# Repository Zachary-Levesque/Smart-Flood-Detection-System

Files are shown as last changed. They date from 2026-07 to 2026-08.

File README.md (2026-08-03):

# Smart Flood Detection System

**ESP32 C3 Mini based IoT flood detection system.** It monitors water level in real time, triggers a local buzzer and LED alarm, sends a Telegram alert over WiFi, and keeps recent events available.

## Motivation

After experiencing a basement flood for the second time in 14 months, I wanted a system that could catch water leakage early and notify me immediately. This project applies embedded design, sensing, connectivity, and reliability thinking to a real home safety problem.

## Overview

This system continuously monitors water presence using a Seeed Studio Grove Water Level Sensor connected to an ESP32 C3 Mini over I2C. When water is detected above the calibrated threshold, the system:

1. Triggers the local buzzer and LED.
2. Sends a Telegram notification when WiFi and credentials are available.
3. Logs the event with a timestamp for later serial review.

The design prioritizes reliability and fail safe behavior.

## System Architecture

Completed Smart Flood Detection System

See [hardware/block_diagram.md](hardware/block_diagram.md) for the completed system image.

## Hardware

1. **Microcontroller:** ESP32 C3 Mini.
2. **Sensor:** Seeed Studio Grove Water Level Sensor 101020635.
3. **Local alert:** Buzzer and status LED.
4. **Power:** 5 V USB wall adapter.
5. **Enclosure:** Simple plastic project box.
6. **PCB:** Simple carrier PCB in [hardware/PCB](hardware/PCB).

## Bill Of Materials

The simple part list is in [hardware/bill_of_materials.md](hardware/bill_of_materials.md).

## Firmware

Firmware is developed for the ESP32 C3 Mini using ESP IDF. It handles:

1. Periodic I2C sensor polling with debounce logic.
2. WiFi connection management and reconnect handling.
3. Threshold based water detection.
4. Local event logging.
5. Task watchdog coverage.
6. Telegram alert delivery when configured.

The local buzzer and LED path is intentionally independent of WiFi. Sensor events are delivered to the local alarm queue before any optional remote alert queue.

## Alerting And Connectivity

When the water threshold is exceeded, the firmware can send a Telegram bot notification directly over HTTPS using ESP IDF `esp_http_client`. If WiFi is unavailable or credentials are not configured, the remote alert is skipped and the local alarm remains active.

## Setup And Installation

Install and source the ESP IDF toolchain, then build, flash, and monitor the firmware from the `firmware` folder. Replace the `CHANGE_ME` values in `firmware/main/app_config.h` locally before flashing. Do not commit real WiFi or Telegram credentials.

## Wiring Diagram

See [hardware/wiring.md](hardware/wiring.md) for the simple pin map.

## Testing And Validation

To ensure this system performs reliably in a real flood scenario, testing includes:

1. Sensor accuracy testing with known dry, damp, wet, and submerged states.
2. False alarm testing with humidity and brief splashes.
3. Connectivity loss testing to confirm the local alarm still triggers without WiFi.
4. Power interruption testing with the selected backup power method.
5. End to end alert latency testing.

Use [hardware/test_plan.md](hardware/test_plan.md) for the simple test steps.

## Results

The prototype design and firmware are complete in this repository. The completed system is implemented and live in my basement!

## Repository Structure

```
Smart Flood Detection System
firmware    ESP32 C3 Mini source code
hardware    Block diagram, part list, wiring, PCB, and test plan
LICENSE
README.md
```

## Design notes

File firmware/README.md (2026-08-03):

# Firmware

This is the ESP IDF project for the Smart Flood Detection System, targeting the ESP32 C3 Mini.

## Task Architecture

The firmware is split into independent FreeRTOS tasks. Sensor state changes are sent to dedicated queues so the local alarm path remains isolated from networking.

1. `sensor_task` polls the Seeed Studio Grove Water Level Sensor over I2C, debounces readings, logs state changes, and sends each `system_event_t` to the local alarm queue first and the remote alert queue second.
2. `alarm_task` consumes its dedicated queue and drives the local buzzer and LED. It has no dependency on WiFi or networking.
3. `alert_task` consumes a separate queue and sends Telegram HTTPS alerts only when `wifi_manager_is_connected()` is true.
4. `wifi_manager` connects to the configured access point and handles automatic reconnect after drops.
5. `event_log` stores timestamped water state events in a RAM ring buffer and can dump the log over serial.

This separation is deliberate. The primary safety function is the local alarm, and it must not depend on remote alerting.

## Production Hardening

1. WiFi credentials are hardcoded in `app_config.h` for the prototype. A production build should use NVS backed WiFi provisioning with BLE or SoftAP setup.
2. `WATER_LEVEL_THRESHOLD_PERCENT` must be set from level readings captured for dry, damp, wet, and submerged states.
3. Long term deployment should use perfboard or a PCB in an enclosure.

## Calibration And Diagnostics

1. Hold `CALIBRATION_MODE_GPIO` low at boot, or set `SENSOR_CALIBRATION_FORCE` to `1`, to stream water level readings over serial while the firmware runs.
2. Hold `EVENT_LOG_DUMP_GPIO` low, or set `EVENT_LOG_DUMP_ON_BOOT` to `1`, to dump the RAM event log over serial.
3. `sensor_logic.c/.h` contains pure threshold and debounce helpers intended for reuse from an ESP IDF unit test app.

## Remote Alerting

Telegram alerting is implemented in `alert_task`. Fill in `TELEGRAM_BOT_TOKEN` and `TELEGRAM_CHAT_ID` in `app_config.h` locally before flashing. Real credentials should not be committed.

## Building

Requires the ESP IDF toolchain installed and sourced. Set the target to esp32c3 before building.

```
idf.py menuconfig
idf.py build
idf.py flash monitor
```

## File Overview

```
firmware
CMakeLists.txt          top level project build file
sdkconfig.defaults      default build configuration
main
  CMakeLists.txt        component build file
  app_config.h          pins, thresholds, WiFi config, shared types
  main.c                app_main wires up tasks
  sensor_task.c/.h      I2C water sensor polling and event fanout
  sensor_logic.c/.h     unit testable threshold and debounce helpers
  alarm_task.c/.h       local buzzer and LED
  alert_task.c/.h       Telegram HTTPS alerting
  event_log.c/.h        RAM event log and serial dump
  wifi_manager.c/.h     WiFi connection and reconnect handling
```

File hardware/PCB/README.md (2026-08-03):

# PCB

This folder contains a simple carrier PCB for the Smart Flood Detection System.

## What The PCB Does

1. Connects the ESP32 C3 Mini to the Grove water level sensor.
2. Connects GPIO6 to the buzzer.
3. Connects GPIO7 to the LED through a 220 ohm resistor.
4. Keeps the circuit cleaner than a breadboard.

## Connectors

1. J1 is the ESP32 C3 Mini signal header.
2. J2 is the Grove sensor connector.
3. J3 is the buzzer connector.
4. R1 is the 220 ohm LED resistor.
5. D1 is the status LED.

## J1 Pin Order

1. 3V3
2. GND
3. GPIO4 SDA
4. GPIO5 SCL
5. GPIO6 buzzer
6. GPIO7 LED

## J2 Grove Pin Order

1. SCL
2. SDA
3. 3V3
4. GND

## Files

1. `gerbers` contains the fabrication files.
2. `board_notes.md` explains the layout in plain language.

Check the exact ESP32 C3 Mini board dimensions before ordering. This is a simple carrier board, not a custom ESP32 module layout.

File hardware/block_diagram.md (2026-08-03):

# Completed System Image

Completed Smart Flood Detection System

The Grove water sensor connects to the ESP32 C3 Mini with I2C. The ESP32 C3 Mini turns on the local buzzer and LED when water is detected. If WiFi is working, it also sends a Telegram alert.

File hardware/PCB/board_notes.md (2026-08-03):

# Board Notes

Board size is 50 mm by 40 mm.

The ESP32 C3 Mini plugs in through the J1 header or connects with short wires. The Grove sensor plugs into J2. The buzzer plugs into J3. The LED and resistor are mounted on the board.

This PCB is meant to replace the breadboard wiring for the current project.

Before ordering, confirm these points:

1. Your ESP32 C3 Mini exposes GPIO4, GPIO5, GPIO6, GPIO7, 3V3, and GND.
2. Your Grove cable pin order matches SCL, SDA, 3V3, and GND.
3. Your buzzer module can be driven from GPIO6.
4. Your LED uses a 220 ohm resistor.

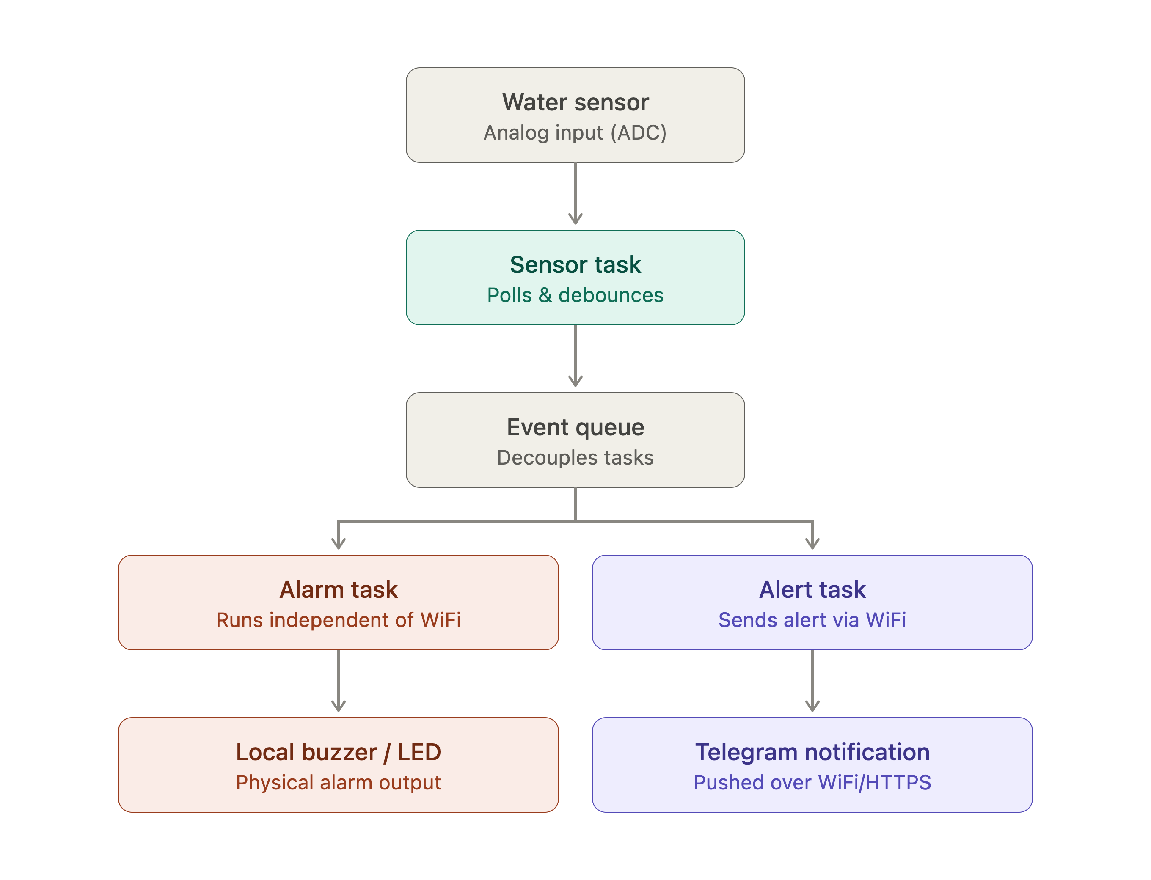
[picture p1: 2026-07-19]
flood_detection_system_architecture.png

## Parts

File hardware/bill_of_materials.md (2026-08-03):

# Bill Of Materials

## Required Parts

1. ESP32 C3 Mini.
2. Seeed Studio Grove Water Level Sensor 101020635.
3. Active buzzer module.
4. LED.
5. 220 ohm resistor for the LED.
6. Jumper wires.
7. Custom carrier PCB.
8. USB cable.
9. 5 V USB power adapter.
10. Plastic enclosure.

## Optional Parts

1. USB battery backup.
2. Extra mounting tape, screws, or zip ties.

## Notes

1. Use the sensor with 3.3 V power from the ESP32 C3 Mini.
2. Keep the ESP32 and wiring above the floor.
3. Keep the water sensor at the lowest point where water should be detected.

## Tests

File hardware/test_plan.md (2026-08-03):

# Test Plan

1. Power on the ESP32 with the sensor dry. The buzzer and LED should stay off.
2. Touch the Grove sensor with water. The buzzer and LED should turn on.
3. Dry the sensor. The buzzer and LED should turn off.
4. Turn off WiFi and wet the sensor. The local alarm should still work.
5. Turn WiFi back on and confirm the Telegram alert works.
6. Leave the system running for a few hours and check for false alarms.

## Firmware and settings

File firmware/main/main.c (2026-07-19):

#include "app_config.h"
#include "alert_task.h"
#include "sensor_task.h"
#include "alarm_task.h"
#include "event_log.h"
#include "wifi_manager.h"

#include "freertos/FreeRTOS.h"
#include "freertos/queue.h"
#include "esp_err.h"
#include "esp_log.h"
#include "esp_task_wdt.h"

static void configure_task_watchdog(void)
{
    esp_task_wdt_config_t wdt_config = {
        .timeout_ms = TASK_WATCHDOG_TIMEOUT_MS,
        .idle_core_mask = 0,
        .trigger_panic = true,
    };

    esp_err_t err = esp_task_wdt_init(&wdt_config);
    if (err == ESP_ERR_INVALID_STATE) {
        ESP_LOGW("main", "Task watchdog already initialized");
    } else {
        ESP_ERROR_CHECK(err);
    }
}

static const char *TAG = "main";

void app_main(void)
{
    ESP_LOGI(TAG, "Smart Flood Detection System starting up");
    event_log_init();
    configure_task_watchdog();

    // Dedicated alarm queue: sensor_task publishes local-alarm events here
    // first. Remote alerting has a separate queue so network work cannot
    // consume, gate, or delay the local alarm path.
    QueueHandle_t alarm_event_queue = xQueueCreate(10, sizeof(system_event_t));
    QueueHandle_t alert_event_queue = xQueueCreate(10, sizeof(system_event_t));
    if (alarm_event_queue == NULL || alert_event_queue == NULL) {
        ESP_LOGE(TAG, "Failed to create event queues, halting");
        return;
    }

    // WiFi is started but never gated on — the local alarm and
    // sensor logic run regardless of network state. This is the
    // core fail-safe design principle of this project: connectivity
    // is a "nice to have" for remote alerting, not a dependency for
    // the physical safety mechanism.
    wifi_manager_start();

    event_log_dump_task_start();
    alarm_task_start(alarm_event_queue);
    alert_task_start(alert_event_queue);
    sensor_task_start(alarm_event_queue, alert_event_queue);
}

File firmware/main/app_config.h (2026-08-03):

#pragma once

#include <stdint.h>

#include "driver/gpio.h"
#include "driver/i2c.h"

// =====================================================================
// Pin configuration
// Prototype pin assignments. These match hardware/wiring.md.
// =====================================================================
#define I2C_PORT                    I2C_NUM_0
#define I2C_SDA_GPIO                GPIO_NUM_4
#define I2C_SCL_GPIO                GPIO_NUM_5
#define BUZZER_GPIO                 GPIO_NUM_6
#define STATUS_LED_GPIO             GPIO_NUM_7
#define CALIBRATION_MODE_GPIO       GPIO_NUM_0   // hold low at boot to stream level readings
#define EVENT_LOG_DUMP_GPIO         GPIO_NUM_0   // hold low to dump recent events over serial

// =====================================================================
// Sensor thresholds
// Calibrate this against real level readings from calibration mode:
// 1. Flash firmware, hold CALIBRATION_MODE_GPIO low at boot, and open monitor.
// 2. Record water level percent for dry, damp, wet, and submerged states.
// 3. Set WATER_LEVEL_THRESHOLD_PERCENT to the level that should trigger alarm.
// =====================================================================
#define GROVE_WATER_LOW_ADDR        0x77
#define GROVE_WATER_HIGH_ADDR       0x78
#define GROVE_WATER_TOUCH_THRESHOLD 100
#define WATER_LEVEL_THRESHOLD_PERCENT 10
#define SENSOR_POLL_INTERVAL_MS     2000    // how often to sample the sensor
#define SENSOR_DEBOUNCE_SAMPLES     3       // consecutive samples required to confirm a reading
#define SENSOR_CALIBRATION_FORCE    0       // set to 1 to always stream level readings

// =====================================================================
// Runtime diagnostics
// =====================================================================
#define EVENT_LOG_CAPACITY          32
#define EVENT_LOG_DUMP_ON_BOOT      0       // set to 1 to dump RAM log at startup
#define EVENT_LOG_DUMP_GPIO_ENABLED 1       // hold EVENT_LOG_DUMP_GPIO low at boot to dump
#define EVENT_LOG_DUMP_POLL_MS      1000

// =====================================================================
// Watchdog
// =====================================================================
#define TASK_WATCHDOG_TIMEOUT_MS    10000

// =====================================================================
// WiFi configuration
// Prototype credentials. For production, move credentials to NVS backed
// provisioning before deployment.
// ESP IDF WiFi provisioning examples support BLE or SoftAP flows that store
// credentials in NVS.
// =====================================================================
#define WIFI_SSID                   "CHANGE_ME"
#define WIFI_PASSWORD                "CHANGE_ME"
#define WIFI_MAX_RETRY               5
#define WIFI_RETRY_BACKOFF_MS        30000

// =====================================================================
// Telegram alerting
// Fill these in locally. Do not commit real bot tokens or chat IDs.
// =====================================================================
#define TELEGRAM_BOT_TOKEN          "CHANGE_ME"
#define TELEGRAM_CHAT_ID            "CHANGE_ME"
#define TELEGRAM_ALERT_MESSAGE      "Water detected by Smart Flood Detection System"

// =====================================================================
// Event types passed between tasks via queue
// =====================================================================
typedef enum {
    EVENT_WATER_NORMAL = 0,
    EVENT_WATER_DETECTED,
} system_event_t;

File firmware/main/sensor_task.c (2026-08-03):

#include "sensor_task.h"
#include "app_config.h"
#include "event_log.h"
#include "sensor_logic.h"

#include "freertos/FreeRTOS.h"
#include "freertos/task.h"
#include "driver/gpio.h"
#include "driver/i2c.h"
#include "esp_err.h"
#include "esp_log.h"
#include "esp_task_wdt.h"

static const char *TAG = "sensor_task";

typedef struct {
    QueueHandle_t alarm_event_queue;
    QueueHandle_t alert_event_queue;
} sensor_task_config_t;

static esp_err_t read_sensor_section(uint8_t address, uint8_t *data, size_t length)
{
    return i2c_master_read_from_device(I2C_PORT,
                                       address,
                                       data,
                                       length,
                                       pdMS_TO_TICKS(100));
}

static int count_touched_sections(const uint8_t *data, size_t length)
{
    int touched = 0;
    for (size_t i = 0; i < length; i++) {
        if (data[i] > GROVE_WATER_TOUCH_THRESHOLD) {
            touched++;
        }
    }
    return touched;
}

static int read_water_level_percent(void)
{
    uint8_t low_data[8] = {0};
    uint8_t high_data[12] = {0};

    esp_err_t low_err = read_sensor_section(GROVE_WATER_LOW_ADDR, low_data, sizeof(low_data));
    esp_err_t high_err = read_sensor_section(GROVE_WATER_HIGH_ADDR, high_data, sizeof(high_data));
    if (low_err != ESP_OK || high_err != ESP_OK) {
        ESP_LOGW(TAG, "Water sensor I2C read failed low=%s high=%s",
                 esp_err_to_name(low_err),
                 esp_err_to_name(high_err));
        return 0;
    }

    int touched = count_touched_sections(low_data, sizeof(low_data)) +
                  count_touched_sections(high_data, sizeof(high_data));
    return touched * 5;
}

static bool calibration_mode_enabled(void)
{
#if SENSOR_CALIBRATION_FORCE
    return true;
#else
    return gpio_get_level(CALIBRATION_MODE_GPIO) == 0;
#endif
}

static void configure_calibration_gpio(void)
{
    gpio_reset_pin(CALIBRATION_MODE_GPIO);
    gpio_set_direction(CALIBRATION_MODE_GPIO, GPIO_MODE_INPUT);
    gpio_set_pull_mode(CALIBRATION_MODE_GPIO, GPIO_PULLUP_ONLY);
}

static void configure_i2c(void)
{
    i2c_config_t config = {
        .mode = I2C_MODE_MASTER,
        .sda_io_num = I2C_SDA_GPIO,
        .scl_io_num = I2C_SCL_GPIO,
        .sda_pullup_en = GPIO_PULLUP_ENABLE,
        .scl_pullup_en = GPIO_PULLUP_ENABLE,
        .master.clk_speed = 100000,
    };

    ESP_ERROR_CHECK(i2c_param_config(I2C_PORT, &config));
    ESP_ERROR_CHECK(i2c_driver_install(I2C_PORT, config.mode, 0, 0, 0));
}

static void publish_event(QueueHandle_t queue, system_event_t event, const char *queue_name)
{
    if (queue == NULL) {
        return;
    }

    if (xQueueSend(queue, &event, pdMS_TO_TICKS(100)) != pdTRUE) {
        ESP_LOGW(TAG, "Failed to enqueue event for %s (queue full)", queue_name);
    }
}

static void sensor_task(void *pvParameters)
{
    sensor_task_config_t *config = (sensor_task_config_t *) pvParameters;
    ESP_ERROR_CHECK(esp_task_wdt_add(NULL));

    configure_i2c();
    configure_calibration_gpio();

    sensor_debounce_state_t debounce;
    sensor_debounce_init(&debounce);

    ESP_LOGI(TAG, "Sensor task started, polling every %d ms", SENSOR_POLL_INTERVAL_MS);

    while (1) {
        int level_percent = read_water_level_percent();

        if (calibration_mode_enabled()) {
            ESP_LOGI(TAG, "Calibration water level: %d percent", level_percent);
        }

        bool changed = false;
        system_event_t current_state = sensor_debounce_update(&debounce,
                                                              level_percent,
                                                              WATER_LEVEL_THRESHOLD_PERCENT,
                                                              SENSOR_DEBOUNCE_SAMPLES,
                                                              &changed);

        if (changed) {
            ESP_LOGI(TAG, "Water state changed: %s (level=%d percent)",
                     system_event_to_string(current_state),
                     level_percent);

            event_log_record(current_state);
            publish_event(config->alarm_event_queue, current_state, "alarm");
            publish_event(config->alert_event_queue, current_state, "alert");
        }

        ESP_ERROR_CHECK(esp_task_wdt_reset());
        vTaskDelay(pdMS_TO_TICKS(SENSOR_POLL_INTERVAL_MS));
    }
}

void sensor_task_start(QueueHandle_t alarm_event_queue, QueueHandle_t alert_event_queue)
{
    static sensor_task_config_t config;
    config.alarm_event_queue = alarm_event_queue;
    config.alert_event_queue = alert_event_queue;

    xTaskCreate(sensor_task, "sensor_task", 4096, (void *) &config, 5, NULL);
}

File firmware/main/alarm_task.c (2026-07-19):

#include "alarm_task.h"
#include "app_config.h"

#include "freertos/FreeRTOS.h"
#include "freertos/task.h"
#include "driver/gpio.h"
#include "esp_err.h"
#include "esp_log.h"
#include "esp_task_wdt.h"

static const char *TAG = "alarm_task";

static void configure_outputs(void)
{
    gpio_reset_pin(BUZZER_GPIO);
    gpio_set_direction(BUZZER_GPIO, GPIO_MODE_OUTPUT);

    gpio_reset_pin(STATUS_LED_GPIO);
    gpio_set_direction(STATUS_LED_GPIO, GPIO_MODE_OUTPUT);
}

static void set_alarm_state(bool active)
{
    gpio_set_level(BUZZER_GPIO, active ? 1 : 0);
    gpio_set_level(STATUS_LED_GPIO, active ? 1 : 0);
}

// This task is intentionally simple and self-contained: it only
// depends on the event queue, not on WiFi/network state, so a local
// alarm still fires during a network outage.
static void alarm_task(void *pvParameters)
{
    QueueHandle_t event_queue = (QueueHandle_t) pvParameters;
    ESP_ERROR_CHECK(esp_task_wdt_add(NULL));

    configure_outputs();
    set_alarm_state(false);

    ESP_LOGI(TAG, "Alarm task started");

    system_event_t event;
    while (1) {
        if (xQueueReceive(event_queue, &event, pdMS_TO_TICKS(1000)) == pdTRUE) {
            bool active = (event == EVENT_WATER_DETECTED);
            ESP_LOGI(TAG, "Setting local alarm state: %s", active ? "ON" : "OFF");
            set_alarm_state(active);
        }
        ESP_ERROR_CHECK(esp_task_wdt_reset());
    }
}

void alarm_task_start(QueueHandle_t event_queue)
{
    xTaskCreate(alarm_task, "alarm_task", 2048, (void *) event_queue, 6, NULL);
}
